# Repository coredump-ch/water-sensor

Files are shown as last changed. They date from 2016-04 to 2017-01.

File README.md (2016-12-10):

# Water Temperature Sensors

## Firmware

The firmware is located in the `electron` directory.

To build:

    $ cd electron
    $ particle login
    $ rm electron_firmware_*.bin
    $ make
    $ particle flash --usb electron_firmware_*.bin

(Support for local toolchain is planned.)

- If `DEBUG_MODE` is set to 1, the data will be logged to serial every 5 seconds.
- If `DEBUG_MODE` is set to 0, the data will be logged to the particle cloud as an event every hour.

## Event data format

The events are logged as events to the particle cloud with the event name `measurement`.

The data contains the measurements as comma separated `key=value` pairs. The
temperature values are returned as decimal milli-degrees celsius.

Keys:

- `t1`: Main temperature sensor
- `v`: Battery voltage
- `c`: Battery capacity (percent)

Here's an example event:

    {
        "data":"t1=24997,v=3.945,c=85.3",
        "ttl":"300",
        "published_at":"2016-04-26T20:55:26.915Z",
        "coreid":"4a005b001451343334363036",
        "name":"measurement"
    }

## Message format (LoRaWAN)

LoRaWAN uses a binary message format. Payload bytes correspond to the following
C struct (bytes in network byte order):

```c
struct {
    uint32_t millicelsius; // Integer like 23420
    float batteryVoltage; // Float like 3.945454
    float batteryCharge; // Charge percentage like 85.38253
} payload;
```

In Python, messages can be parsed using the `!iff` format specifier:

```python
import struct
struct.unpack(̈́'!iff', payload)
```

TO DISCUSS:

- Do we want a binary format, or stick with ascii strings?
- If we want a binary format, how do we keep it upgradeable?

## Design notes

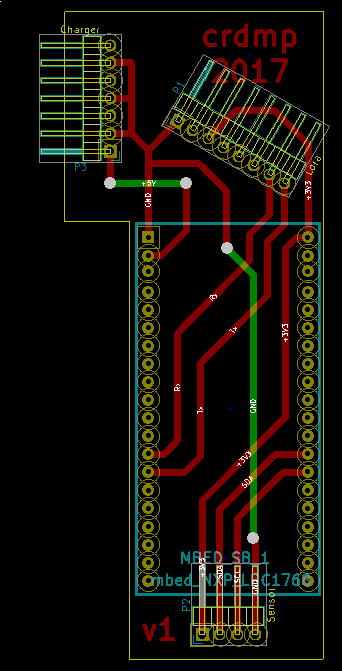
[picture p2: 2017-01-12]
hardware/v1/export-v1/screenshot.png

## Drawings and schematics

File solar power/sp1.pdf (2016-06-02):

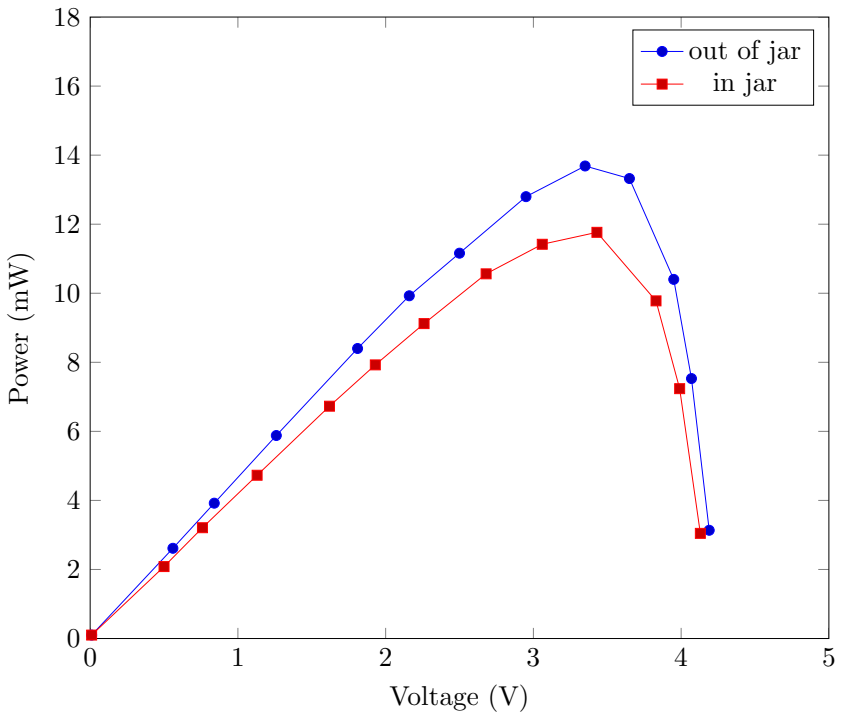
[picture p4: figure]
Voltage (V); Power (mW); out of jar in jar

Figure 1: Power vs. voltage for Solar Panel 1 in overcast conditions

1

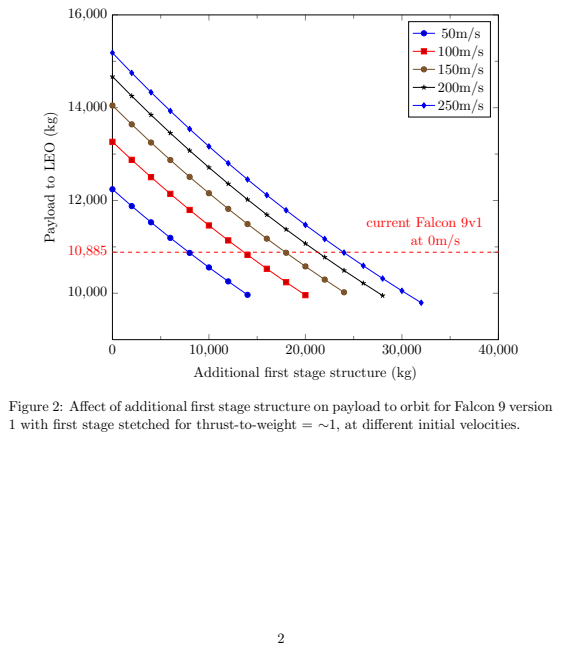
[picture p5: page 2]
current Falcon 9v1 at 0m/s

Payload to LEO (kg)

Additional first stage structure (kg)

Figure 2: Affect of additional first stage structure on payload to orbit for Falcon 9 version
1 with first stage stetched for thrust-to-weight = ∼1, at different initial velocities.

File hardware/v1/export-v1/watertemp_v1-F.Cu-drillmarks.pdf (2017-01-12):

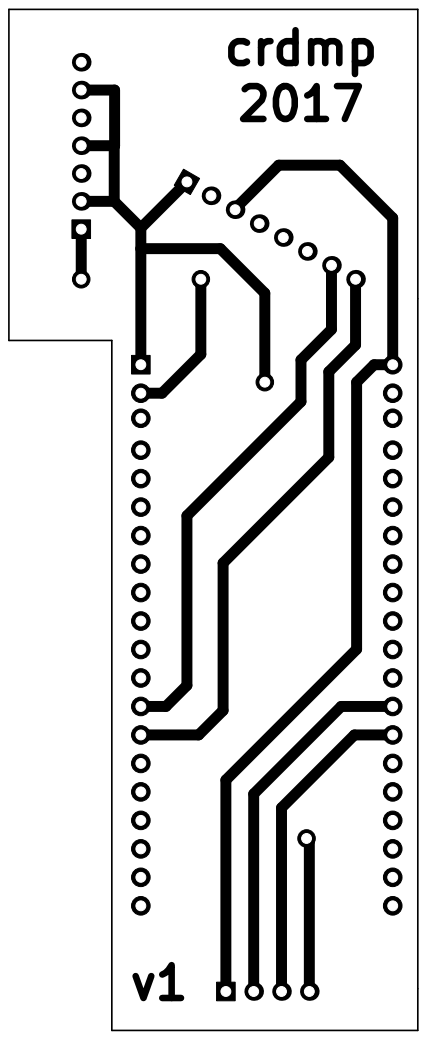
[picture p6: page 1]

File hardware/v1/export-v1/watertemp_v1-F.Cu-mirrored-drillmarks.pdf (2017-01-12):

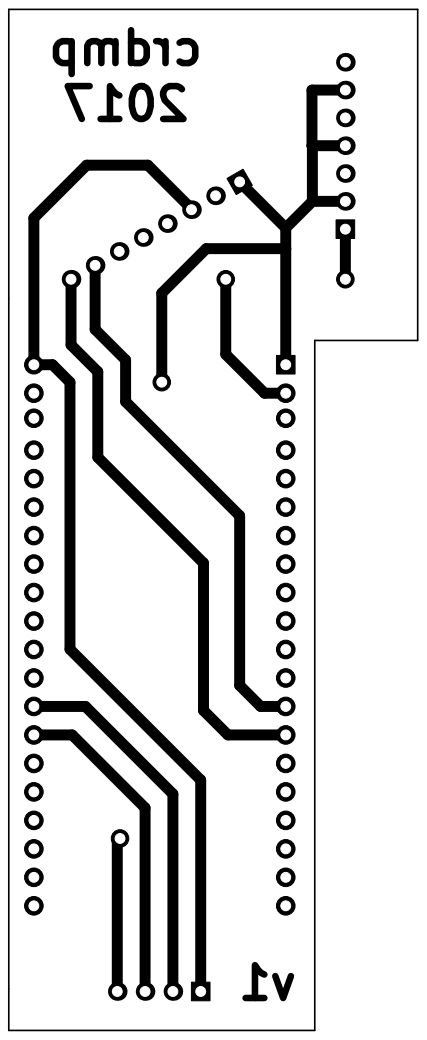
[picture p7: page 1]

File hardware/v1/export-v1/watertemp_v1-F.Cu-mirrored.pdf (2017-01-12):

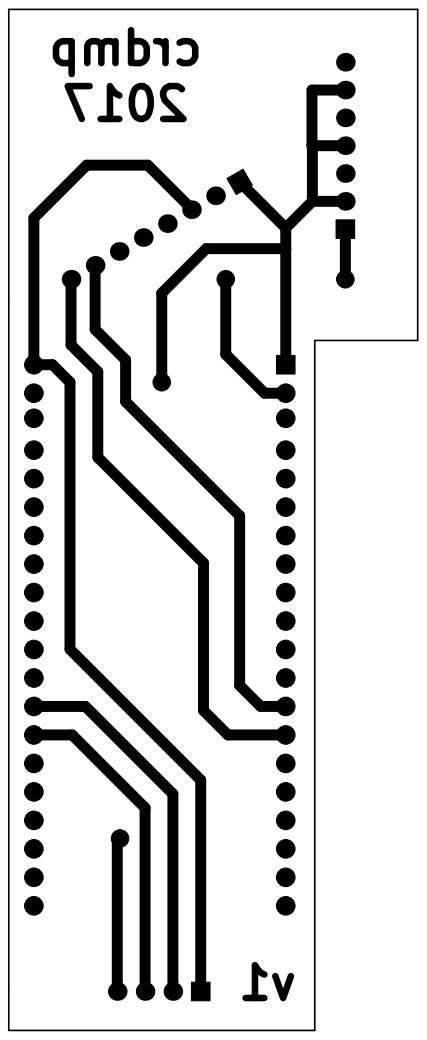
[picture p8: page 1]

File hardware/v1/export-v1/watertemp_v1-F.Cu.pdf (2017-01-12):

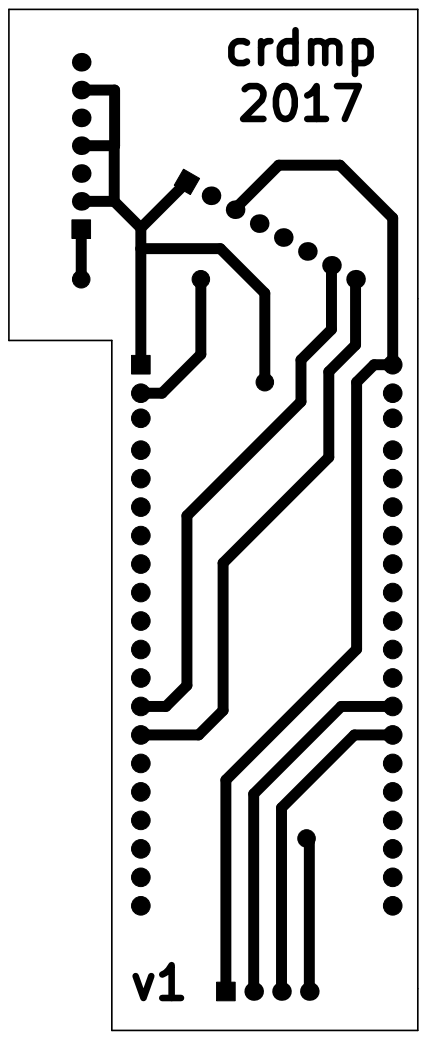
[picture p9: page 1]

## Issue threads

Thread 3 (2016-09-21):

Choose a micro-controller

rnestler, 2016-09-21:
We need to find a suiting micro-controller.

The following features would be nice:
- ARM based
- [openocd](http://openocd.org/) support
- mbed compatible
- cheap
- low-power

Options:
- [LPC11U12FBD48/201](http://www.digikey.com/product-detail/en/nxp-semiconductors/LPC11U12FBD48-201,/568-8582-ND/2791874)
- [LPC11U24FHI33/301](http://www.digikey.com/product-detail/en/nxp-semiconductors/LPC11U24FHI33-301,/568-8523-ND/2772164)

dbrgn, 2016-09-27:
We'll use this one:

- IC MCU 32BIT 32KB FLASH 48LQFP
- Model: LPC11U24FBD48/401
- Package: 48-LQFP
- Digikey: 568-8460-ND
- Price: USD 3.71

https://www.digikey.com/product-detail/en/nxp-semiconductors/LPC11U24FBD48-401,/568-8460-ND/2771727

rnestler, 2016-09-27:
Debugging: https://sourceforge.net/projects/lpc21isp/

Closed 2017-06-05.

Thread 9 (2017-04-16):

Add CRC-Check for OneWire

dbrgn, 2017-04-16:
Just got this measurement:

> DS Temp: -0.06°C | SHT Temp: 25.09°C | SHT Humi: 40.62%RH

That DS temperature occurs if there's a CRC failed check. We need to check that. If it fails, retry measuring 1 or 2 times.

dbrgn, 2017-04-16:
Ah, actually the cable came loose. But according to my experience it can also appear intermittently.

We should probably also decide on something to send if the measurement fails, e.g. NaN.

dbrgn, 2018-05-18:
Closing since we moved the repo to the gfroerli organization.

Closed 2018-05-18.

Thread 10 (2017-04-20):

Add battery meter

dbrgn, 2017-04-20:
We should be able to track the battery voltage and/or charge in percent.

rnestler, 2017-04-20:
Didn't we plan to have like a battery management system which manages all this and provides the charge?

dbrgn, 2017-04-20:
The board by Adafruit unfortunately only reports a binary battery low warning, but no voltage level.

dbrgn, 2017-08-15:
Closed in favor of https://github.com/coredump-ch/watertemp-hardware/issues/4

Closed 2017-08-15.

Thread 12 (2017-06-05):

Expose RN2483 ICSP header

dbrgn, 2017-06-05:
...so that we can do firmware upgrades.

http://ww1.microchip.com/downloads/en/DeviceDoc/50002346C.pdf Page 9

dbrgn, 2017-07-22:
Fixed in e83926c6a4554260f831f90b7cd2e0008de7073a.

Closed 2017-07-22.

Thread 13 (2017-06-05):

Verify that JTAG connector is correct

dbrgn, 2017-06-05:
https://www.segger.com/interface-description.html

dbrgn, 2017-08-15:
@rnestler can you verify this?

dbrgn, 2017-08-15:
Closed in favor of https://github.com/coredump-ch/watertemp-hardware/issues/3

Closed 2017-08-15.

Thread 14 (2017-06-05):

Expose RN2483 input pins

dbrgn, 2017-06-05:
...so that we can connect an external board.

The board should still work if the RN is not soldered on!

dbrgn, 2017-07-22:
Fixed in 195093564704ffe1bf46ca64b102af3de42e0300

Closed 2017-07-22.

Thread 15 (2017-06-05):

Add 3 LEDs to the dev board

dbrgn, 2017-06-05:
For testing purposes. Limit them to 2-3 mA.

dbrgn, 2017-07-22:
470 Ohm should be fine. That way, even if a LED has a forward voltage of 1.8V, only ~3.2 mA are drawn.

The brightness is definiely enough. Tested experimentally 😆

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

dbrgn, 2017-07-22:
Fixed in f815b4d9b963bf8dd770d15d4834dead0aff5249

Closed 2017-07-22.

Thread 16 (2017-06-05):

Add serial connector

dbrgn, 2017-06-05:
For debugging.

dbrgn, 2017-07-22:
Fixed in 5b2c9c12ff0193f81c8698c2ea8bf62502901f10.

Closed 2017-07-22.

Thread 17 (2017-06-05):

Add I2C connector

dbrgn, 2017-06-05:
For possibly testing with other sensors.

Don't forget pullups.

dbrgn, 2017-07-22:
Fixed in 58a514e08c57cfe3470750a5258039be7fdaf1f8

Closed 2017-07-22.

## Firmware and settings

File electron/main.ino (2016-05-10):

// Firmware for water temperature sensor on the Particle Electron.
//
// (c) 2016 Coredump Rapperswil. Licensed under MIT license.

// Set this to 1 for debug output via serial (9600 baud)
#define DEBUG_MODE 1

// I2C address of the SHT sensor
int shtAddress = 0x40;

// Constants
const int SHT21_TRIG_RH_MEASUREMENT_HM = 0xe5;
const int SHT21_TRIG_T_MEASUREMENT_NHM = 0xf3;

// This will be run once
void setup() {

    // Set I2C frequency to 50 KHz
    Wire.setSpeed(50000);

    // Enable clock stretching (TODO rnestler: maybe remove to save energy?)
    Wire.stretchClock(true);

    // Enable I2C
    Wire.begin();

#if DEBUG_MODE
    Particle.disconnect();
    Serial.begin(9600);
#endif

}

// This will be run in a loop
void loop() {

#if DEBUG_MODE
    Serial.println("mi wile toki!");
#endif

    // Request a temperature measurement from the sensor
    Wire.beginTransmission(shtAddress);
    Wire.write(SHT21_TRIG_T_MEASUREMENT_NHM);
    Wire.endTransmission();

#if DEBUG_MODE
    Serial.println("mi wile sona e pilin seli anu lete!");
#endif

    // Request to read 3 bytes (hi, lo, crc).
    delay(100); // TODO
    if (Wire.requestFrom(shtAddress, 3) == 0) {
#if DEBUG_MODE
        Serial.println("I2C read request timeout");
#else
        Particle.publish("i2c-error", "I2C read request timeout", 60, PRIVATE);
#endif
    }

    if (Wire.available()) {
        // Get battery stats
        FuelGauge fuel;
        float batteryVoltage = fuel.getVCell(); // Actual voltage
        float batteryChargeLevel = fuel.getSoC(); // Percentage, 0-100

#if DEBUG_MODE
        Serial.println("Battery voltage: " + String(batteryVoltage) + ", SoC: " + String(batteryChargeLevel));
#endif

        // Read temperature (16 bit, high then low bits)
        uint8_t temp[2];
        temp[0] = Wire.read(); // hi
        temp[1] = Wire.read(); // lo

        // Read CRC
        uint8_t crc = Wire.read();

        // Validate checksum
        if (!sht2x_crc_valid(temp, 2, crc)) {
            // CRC validation failed
            String data = String::format("data=%0x%0x,crc=%0x", temp[0], temp[1], crc);
#if DEBUG_MODE
            Serial.println("CRC checksum failed.");
            Serial.println(data);
#else
            Particle.publish("crc-error", data, 60, PRIVATE);
#endif
        } else {
            // CRC validation successful. Calculate temperature.
            int32_t val = temp[0] << 8 | temp[1];
            int32_t mcelsius = ((val * 21965) >> 13) - 46850;

            // Notify user
#if DEBUG_MODE
            Serial.print("hi=");
            Serial.print(temp[0], HEX);
            Serial.print(" lo=");
            Serial.print(temp[1], HEX);
            Serial.print("\nval=");
            Serial.print(val, HEX);
            Serial.print("\ntemp=");
            Serial.print(mcelsius);
            Serial.print('\n');
#else
            String data = String::format("t1=%d,v=%.3f,c=%.1f",
                    mcelsius, batteryVoltage, batteryChargeLevel);
            Particle.publish("measurement", data, 300, PRIVATE);
#endif
        }

    }

#if DEBUG_MODE
    delay(5000);
#else
    delay(1000); // Wait for data to be sent. TODO: Make this nicer than a delay.
    System.sleep(SLEEP_MODE_DEEP, 60); // Sleep for 1h
#endif
}

/**
 * Taken directly from Sensirion SHT21 sample code.
 */
const uint16_t POLYNOMIAL = 0x131; // P(x)=x^8+x^5+x^4+1 = 100110001
bool sht2x_crc_valid(uint8_t data[], uint8_t nbrOfBytes, uint8_t checksum) {
    uint8_t crc = 0;
    uint8_t byteCtr;
    // Calculates 8-Bit checksum with given polynomial
    for (byteCtr = 0; byteCtr < nbrOfBytes; ++byteCtr) {
        crc ^= (data[byteCtr]);
        for (uint8_t bit = 8; bit > 0; --bit) {
            if (crc & 0x80) {
                crc = (crc << 1) ^ POLYNOMIAL;
            } else {
                crc = (crc << 1);
            }
        }
    }
    return crc == checksum;
}

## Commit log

2016-04-12 Actually measure SHT21 temperature
2016-05-10 Report battery details
2016-08-09 Switch to platformio to build the firmware
    platformio is a cross platform embedded build tool. See platformio.org for more
    information.
2016-09-21 Add KiCad PCB project
    Once more we start an epic adventure in trying to use KiCad. Hopefully
    by starting with version 4.0 we won't have many problems :)
    [watertemp_v1.kicad_pcb, watertemp_v1.sch]
2016-11-15 firmware: Read both attached sensors
2016-11-15 firmware: Uppercase I2C address
2017-01-10 Initial schematic of the first prototype
    [watertemp_v1.sch]
2017-01-10 Annotate power flags and not connected pins
    [watertemp_v1.sch]
2017-01-10 Add footprints and netlist
    [watertemp_v1.sch]
2017-01-10 Initial PCB
    [watertemp_v1.kicad_pcb]
2017-01-10 PCB layouting
    [watertemp_v1.kicad_pcb]
2017-01-10 Add text to PCB
    [watertemp_v1.kicad_pcb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]
2017-01-12 More export formats
    [watertemp_v1.kicad_pcb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]
2017-01-12 Unified drill hole sizes
    [watertemp_v1.kicad_pcb]
2017-01-12 Update output files
    [watertemp_v1-Edge.Cuts.gbr, watertemp_v1-F.Cu.gbr, watertemp_v1.drl]
